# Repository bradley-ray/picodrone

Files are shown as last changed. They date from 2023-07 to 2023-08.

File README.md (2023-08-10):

# Pico Quadcopter Drone

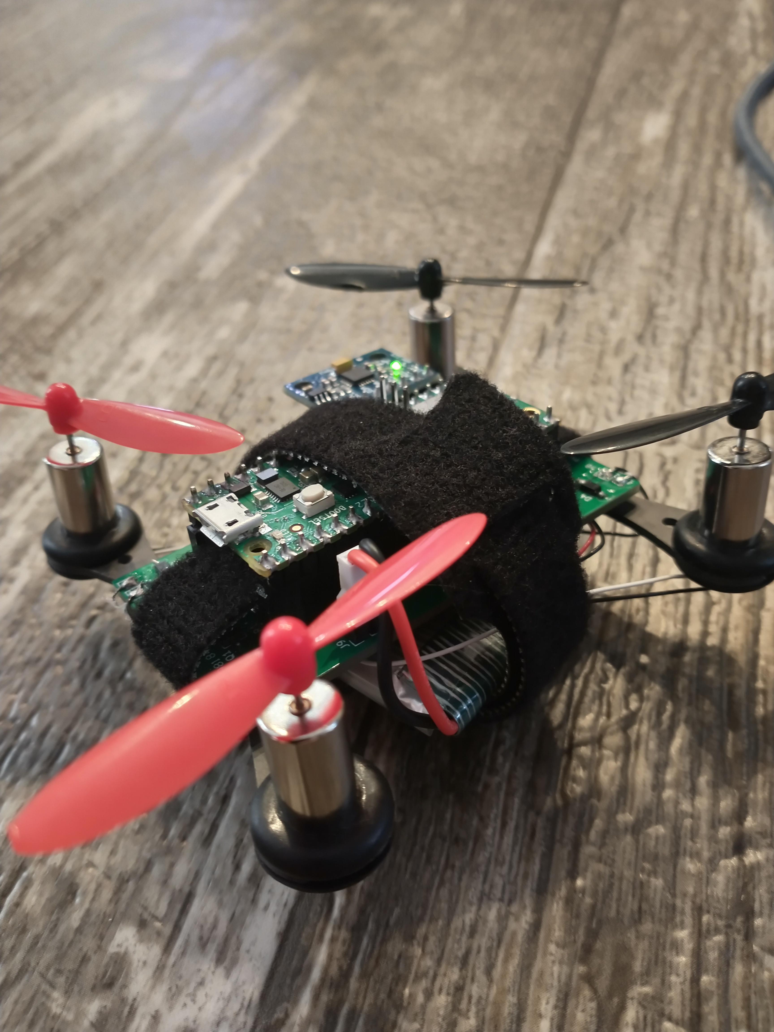
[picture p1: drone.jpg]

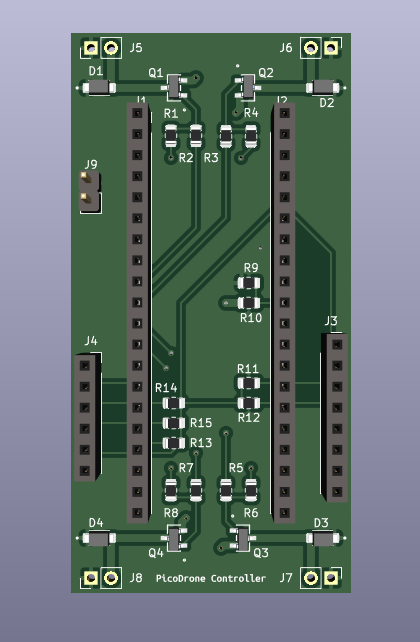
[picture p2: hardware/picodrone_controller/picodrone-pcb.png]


- `hardware/` contains the kicad schematic and pcb layout files 
    - qx95 drone frame
    - 8520 brushed motors
    - header sockets for raspberry pi pico
    - header sockets for mpu 6050 breakout board
    - header sockets for sd card spi breakout board (future use)

- `firmware/` contains the code for the microcontroller
    - requires pico_sdk to be downloaded and PICO_SDK_PATH to be set
    - uses `btstack` and bluetooth rfcomm to receive control commands over bluetooth connection

- `app/` contains python script to send inputs from ps4 controller to drone
    - install `pyPS4Controller` and `pySerial`
    - find pico_w bt addr using `sdptool browse`
    - run `rfcomm connect /dev/rfcomm0 <btaddr>` to connect to the drone
    - run `python3 main.py rfcomm0`
    - connect ps4 controller
        - `triangle` - increase pitch
        - `cross` - decrease pitch
        - `square` - roll left
        - `circle` - roll right
        - `up arrow` - increase throttle
        - `down arrow` - decrease throttle
        - `left arrow` - yaw left
        - `right arrow` - yaw right

## TODO
- need to fix value drift on imu
- need a filter or something for improved imu data
- need to continue and test and adjust pid values

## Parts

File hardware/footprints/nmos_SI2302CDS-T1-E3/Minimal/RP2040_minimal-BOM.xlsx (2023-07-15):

RP2040_minimal_r1 BOM
Item | Quantity | Reference | Part | Voltage | Current | Power | Material | Size | Tolerance | Manufacturer | Manuf. Part # | Description | Notes
1 | 3 | C1,C4,C17 | 10u | 16V |  |  | X5R | 0805_2012Metric | 10% | Murata | GRM21BR61C106KE15K | CAP CER 10UF 16V X5R 0805 | Or equivalent
2 | 2 | C2, C3 | 27p | 50V |  |  | C0G | 0402_1005Metric | 5% | Murata | GCM1555C1H270JA16D | CAP CER 27PF 50V C0G/NP0 0402 | Or equivalent
3 | 10 | C5, C6, C7, C9, C11, C12, C13, C14, C15, C16 | 100n | 25V |  |  | X7R | 0402_1005Metric | 10% | Murata | GRM155R71E104KE14J | CAP CER 0.1UF 25V X7R 0402 | Or equivalent
4 | 2 | C8, C10 | 1u | 10V |  |  | X6S | 0402_1005Metric | 10% | Murata | GRM155C81A105KA12D | CAP CER 1UF 10V X6S 0402 | Or equivalent
5 | 1 | J1 | USB_B_Micro |  |  |  |  |  |  | Amphenol | 10103594-0001LF | CONN RCPT USB2.0 MICRO B SMD R/A | Or equivalent
6 | 1 | J2 | 1x2 way header |  |  |  |  |  |  | Samtec | TSW-102-23-T-S | 2.54mm pin header 1x2 | Or equivalent
7 | 2 | J3, J4 | 2x18 way header |  |  |  |  |  |  | Samtec | TSW-118-23-T-D | 2.54mm pin header 2x18 | Or equivalent
8 | 2 | R1, R5 | 1k |  |  | 63mW |  | 0402_1005Metric | 1% | Yageo | RC0402FR-071KP | RES SMD 1K OHM 1% 1/16W 0402 | Or equivalent
9 | 1 | R2 | DNF |  |  |  |  | 0402_1005Metric |  |  |  |  | Do Not Fit
10 | 2 | R3, R4 | 27.4 |  |  | 63mW |  | 0402_1005Metric | 1% | Yageo | RC0402FR-0727R4L | RES SMD 27.4 OHM 1% 1/16W 0402 | Or equivalent
11 | 1 | U1 | NCP1117-3.3 |  |  |  |  | SOT-223-3 |  | ON Semiconductor | NCP1117ST33T3G | IC REG LINEAR 3.3V 1A SOT223
12 | 1 | U2 | W25Q128JVS |  |  |  |  | SOIC-8 |  | Winbond | W25Q128JVSIQ TR | IC FLASH 128M SPI 133MHZ 8SOIC
13 | 1 | U3 | RP2040 |  |  |  |  | QFN56 |  | Raspberry Pi | RP2040
14 | 1 | Y1 | ABLS-12.000MHZ-B4-T |  |  |  |  | HC49-US |  | Abracon | ABLS-12.000MHZ-B4-T | CRYSTAL 12.0000MHZ 18PF SMD

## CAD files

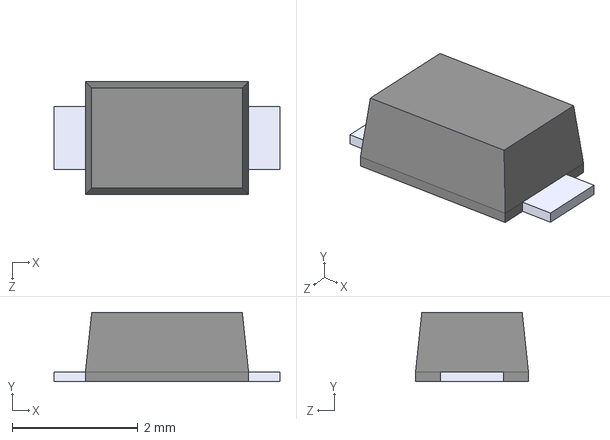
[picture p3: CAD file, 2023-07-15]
hardware/footprints/schottky_DSS16UTR/DSS16UTR.step
3.60 x 1.10 x 1.80 mm

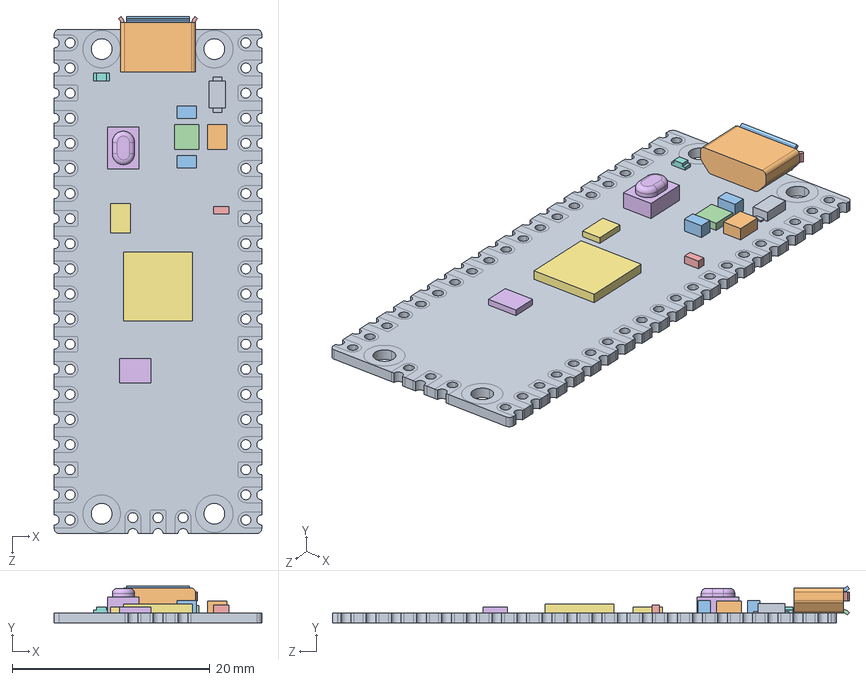
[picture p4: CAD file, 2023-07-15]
hardware/steps/pi-step/Pico-R3.step
21.0 x 3.73 x 52.3 mm
PICO_REF_BOARD.STEP
PICO_REF_USB.STEP
PICO_REF_SWITCH.STEP
PICO_REF_MICROCONTROLLER.STEP
PICO_REF_LED.STEP
PICO_REF_ONSEMI.STEP
PICO_BOURNS.STEP
PICO_MURATA.STEP x 2
PICO_RICHTEK.STEP
PICO_DIODES.STEP
PICO_AEL.STEP
PICO_WINBOND.STEP

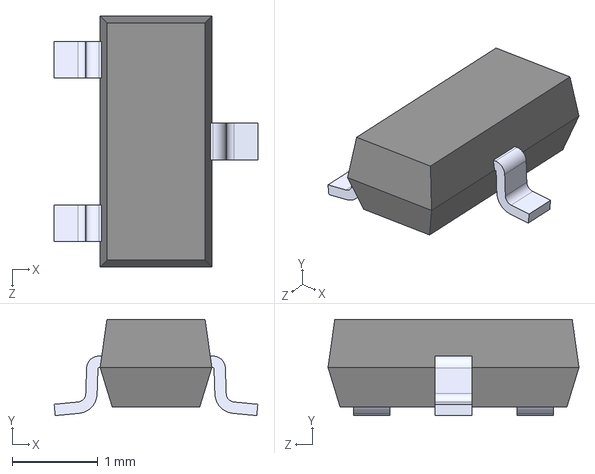
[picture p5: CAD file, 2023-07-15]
hardware/steps/nmos_SI2302CDS-T1-E3.STEP
2.37 x 1.12 x 2.92 mm

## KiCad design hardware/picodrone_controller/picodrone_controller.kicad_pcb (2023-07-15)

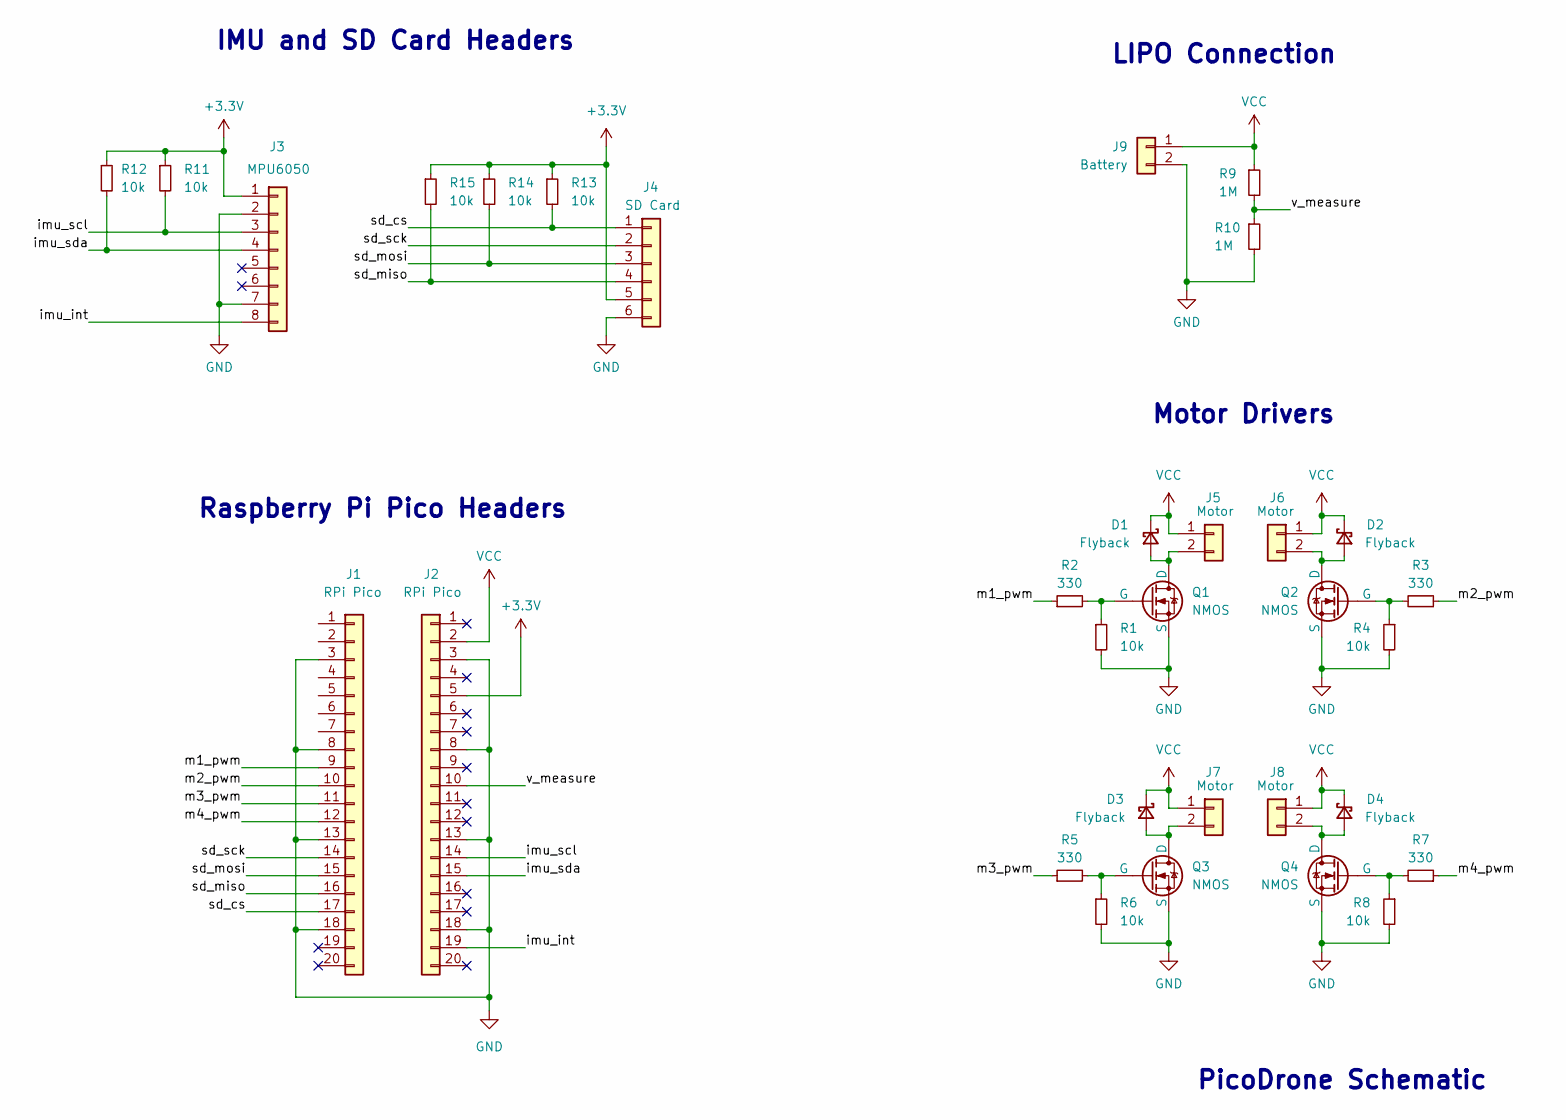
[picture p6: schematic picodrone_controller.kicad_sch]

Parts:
D1, D2, D3, D4: Flyback; SODFL3618X110N
J1, J2: RPi Pico; PinSocket_1x20_P2.54mm_Vertical
J3: MPU6050; PinSocket_1x08_P2.54mm_Vertical
J4: SD Card; PinSocket_1x06_P2.54mm_Vertical
J5, J6, J7, J8: Motor; PinHeader_1x02_P2.54mm_Vertical
J9: Battery; PinHeader_1x02_P2.54mm_Vertical
Q1, Q2, Q3, Q4: NMOS; TO-236_VIS
R1, R4, R6, R8, R11, R12, R13, R14, R15: 10k; R_0805_2012Metric
R2, R3, R5, R7: 330; R_0805_2012Metric
R9, R10: 1M; R_0805_2012Metric

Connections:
+3.3V: J2.5, J3.1, J4.5, R11.1, R12.1, R13.1, R14.1, R15.1
/imu_int: J2.19, J3.8
/imu_scl: J2.14, J3.3, R11.2
/imu_sda: J2.15, J3.4, R12.2
/m1_pwm: J1.9, R2.1
/m2_pwm: J1.10, R3.1
/m3_pwm: J1.11, R5.1
/m4_pwm: J1.12, R7.1
/sd_cs: J1.17, J4.1, R13.2
/sd_miso: J1.16, J4.4, R15.2
/sd_mosi: J1.15, J4.3, R14.2
/sd_sck: J1.14, J4.2
/v_measure: J2.10, R9.2, R10.1
GND: J1.3, J1.8, J1.13, J1.18, J2.3, J2.8, J2.13, J2.18, J3.2, J3.7, J4.6, J9.2, Q1.3 (S), Q2.3 (S), Q3.3 (S), Q4.3 (S), R1.2, R4.2, R6.2, R8.2, R10.2
unnamed: D1.2 (A), J5.2, Q1.1 (D)
unnamed: D2.2 (A), J6.2, Q2.1 (D)
unnamed: D3.2 (A), J7.2, Q3.1 (D)
unnamed: D4.2 (A), J8.2, Q4.1 (D)
unnamed: Q1.2 (G), R1.1, R2.2
unnamed: Q2.2 (G), R3.2, R4.1
unnamed: Q3.2 (G), R5.2, R6.1
unnamed: Q4.2 (G), R7.2, R8.1
VCC: D1.1 (K), D2.1 (K), D3.1 (K), D4.1 (K), J2.2, J5.1, J6.1, J7.1, J8.1, J9.1, R9.1

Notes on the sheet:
Motor Drivers
Raspberry Pi Pico Headers
PicoDrone Schematic
LIPO Connection
IMU and SD Card Headers

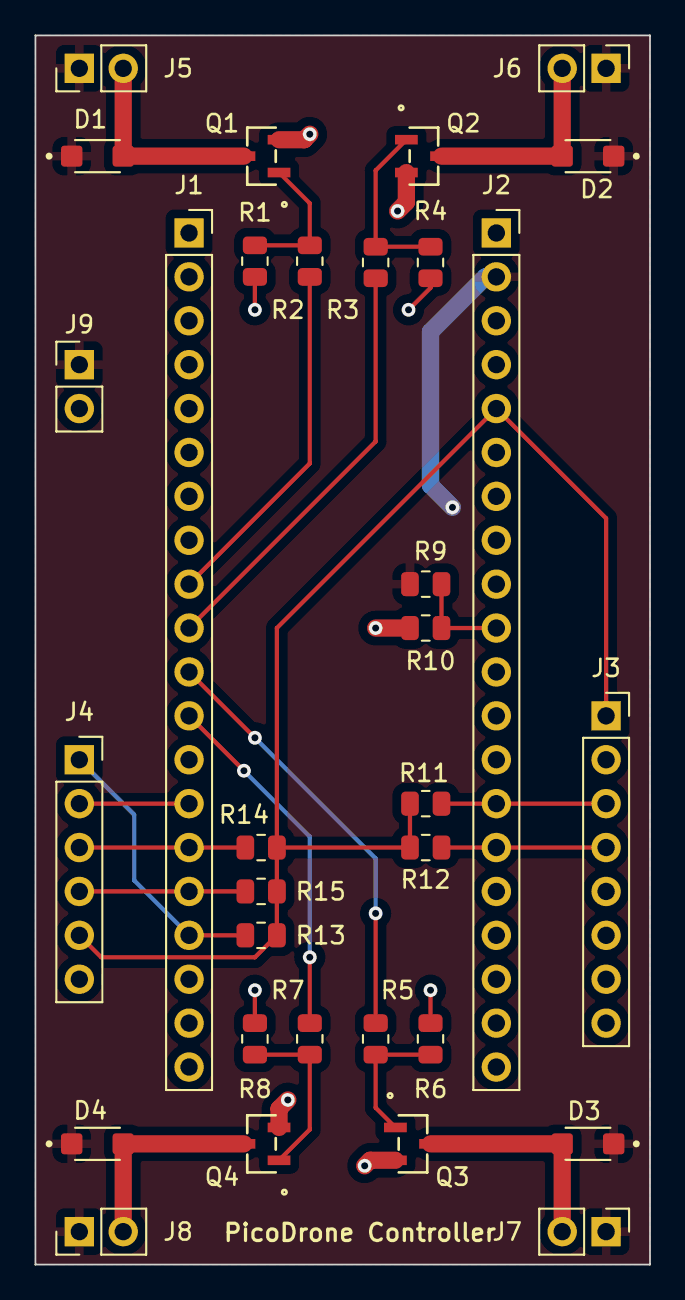
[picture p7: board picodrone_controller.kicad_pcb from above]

Board: 2 copper layers, 35.6 x 71.1 mm, 32 parts (0 on the bottom side), 22 nets.

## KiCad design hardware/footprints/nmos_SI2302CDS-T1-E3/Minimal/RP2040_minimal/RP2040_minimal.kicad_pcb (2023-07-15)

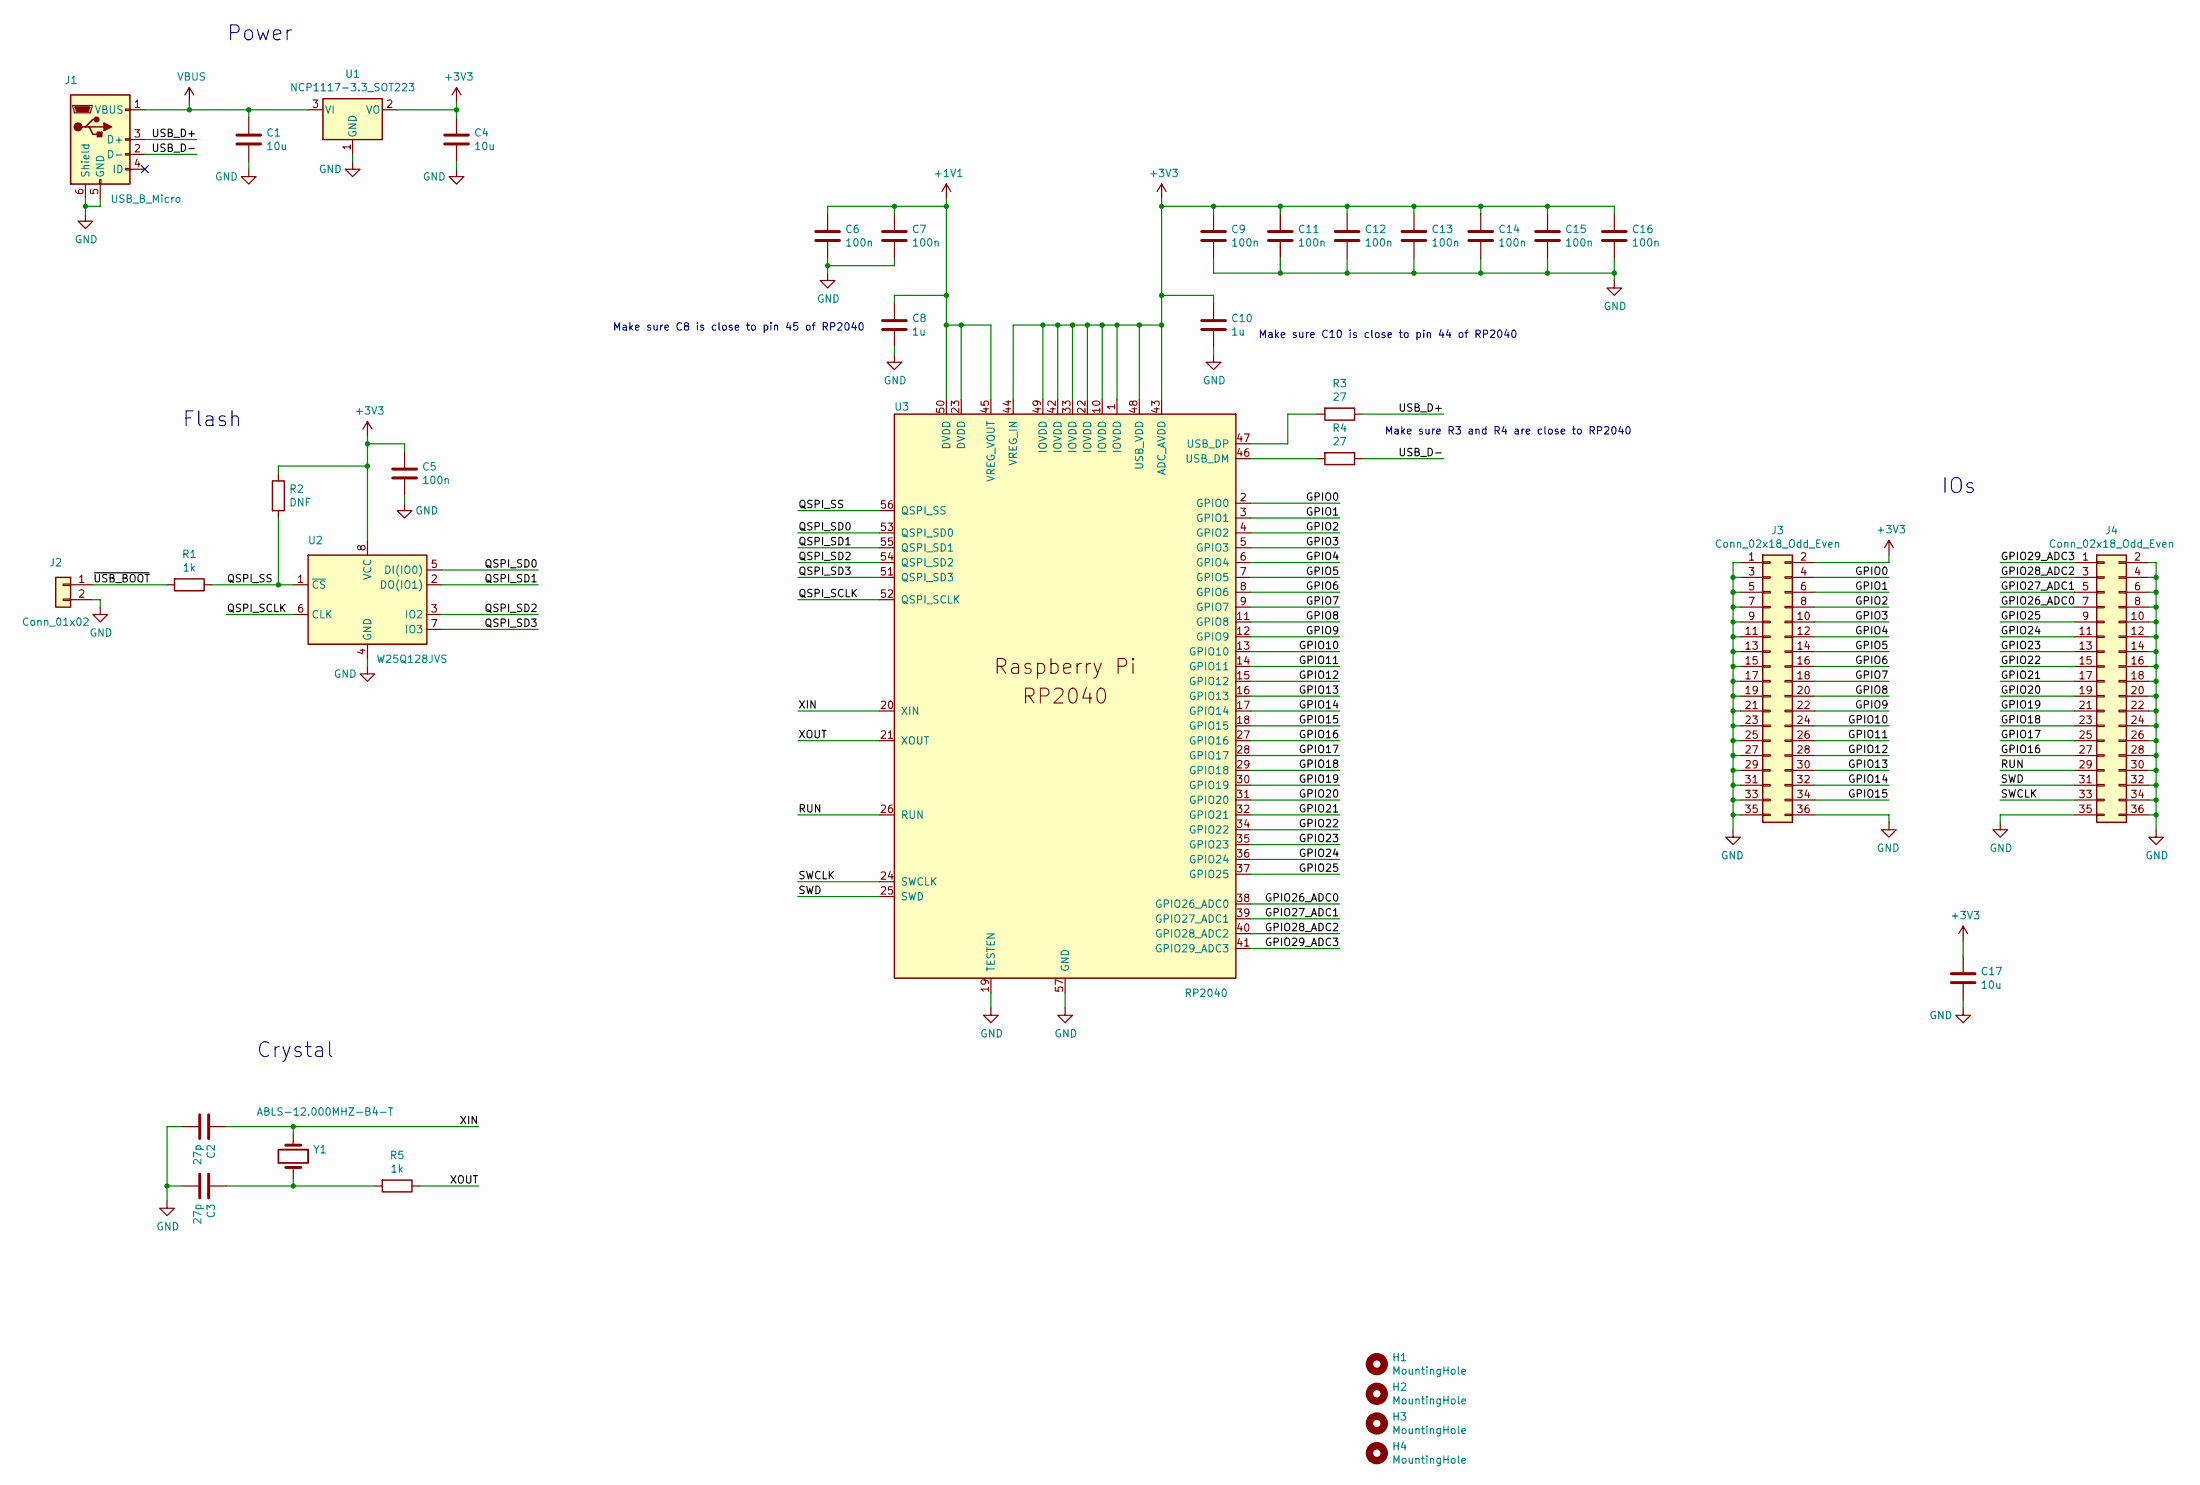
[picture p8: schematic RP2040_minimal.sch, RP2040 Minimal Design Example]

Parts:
C1, C4, C17: 10u; C_0805_2012Metric
C2, C3: 27p; C_0402_1005Metric
C5, C6, C7, C9, C11, C12, C13, C14, C15, C16: 100n; C_0402_1005Metric
C8, C10: 1u; C_0402_1005Metric
H1, H2, H3, H4: MountingHole; MountingHole_2.7mm_M2.5
J1: USB_B_Micro; USB_Micro-B_Amphenol_10103594-0001LF_Horizontal_modified
J2: Conn_01x02; PinHeader_1x02_P2.54mm_Vertical
J3, J4: Conn_02x18_Odd_Even; PinHeader_2x18_P2.54mm_Vertical
R1, R5: 1k; C_0402_1005Metric
R2: DNF; C_0402_1005Metric
R3, R4: 27; C_0402_1005Metric
U1: NCP1117-3.3_SOT223; SOT-223-3_TabPin2
U2: W25Q128JVS; SOIC-8_5.23x5.23mm_P1.27mm
U3: RP2040; RP2040-QFN-56
Y1: ABLS-12.000MHZ-B4-T; Crystal_SMD_HC49-US

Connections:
+1V1: C6.1, C7.1, C8.1, U3.23 (DVDD), U3.45 (VREG_VOUT), U3.50 (DVDD)
+3V3: C4.1, C5.1, C9.1, C10.1, C11.1, C12.1, C13.1, C14.1, C15.1, C16.1, C17.1, J3.2, R2.1, U1.2 (VO), U2.8 (VCC), U3.1 (IOVDD), U3.10 (IOVDD), U3.22 (IOVDD), U3.33 (IOVDD), U3.42 (IOVDD), U3.43 (ADC_AVDD), U3.44 (VREG_IN), U3.48 (USB_VDD), U3.49 (IOVDD)
/GPIO0: J3.4, U3.2 (GPIO0)
/GPIO1: J3.6, U3.3 (GPIO1)
/GPIO2: J3.8, U3.4 (GPIO2)
/GPIO3: J3.10, U3.5 (GPIO3)
/GPIO4: J3.12, U3.6 (GPIO4)
/GPIO5: J3.14, U3.7 (GPIO5)
/GPIO6: J3.16, U3.8 (GPIO6)
/GPIO7: J3.18, U3.9 (GPIO7)
/GPIO8: J3.20, U3.11 (GPIO8)
/GPIO9: J3.22, U3.12 (GPIO9)
/GPIO10: J3.24, U3.13 (GPIO10)
/GPIO11: J3.26, U3.14 (GPIO11)
/GPIO12: J3.28, U3.15 (GPIO12)
/GPIO13: J3.30, U3.16 (GPIO13)
/GPIO14: J3.32, U3.17 (GPIO14)
/GPIO15: J3.34, U3.18 (GPIO15)
/GPIO16: J4.27, U3.27 (GPIO16)
/GPIO17: J4.25, U3.28 (GPIO17)
/GPIO18: J4.23, U3.29 (GPIO18)
/GPIO19: J4.21, U3.30 (GPIO19)
/GPIO20: J4.19, U3.31 (GPIO20)
/GPIO21: J4.17, U3.32 (GPIO21)
/GPIO22: J4.15, U3.34 (GPIO22)
/GPIO23: J4.13, U3.35 (GPIO23)
/GPIO24: J4.11, U3.36 (GPIO24)
/GPIO25: J4.9, U3.37 (GPIO25)
/GPIO26_ADC0: J4.7, U3.38 (GPIO26_ADC0)
/GPIO27_ADC1: J4.5, U3.39 (GPIO27_ADC1)
/GPIO28_ADC2: J4.3, U3.40 (GPIO28_ADC2)
/GPIO29_ADC3: J4.1, U3.41 (GPIO29_ADC3)
/QSPI_SCLK: U2.6 (CLK), U3.52 (QSPI_SCLK)
/QSPI_SD0: U2.5 (DI(IO0)), U3.53 (QSPI_SD0)
/QSPI_SD1: U2.2 (DO(IO1)), U3.55 (QSPI_SD1)
/QSPI_SD2: U2.3 (IO2), U3.54 (QSPI_SD2)
/QSPI_SD3: U2.7 (IO3), U3.51 (QSPI_SD3)
/QSPI_SS: R1.1, R2.2, U2.1 (~CS), U3.56 (QSPI_SS)
/RUN: J4.29, U3.26 (RUN)
/SWCLK: J4.33, U3.24 (SWCLK)
/SWD: J4.31, U3.25 (SWD)
/USB_D+: J1.3 (D+), R3.1
/USB_D-: J1.2 (D-), R4.1
/XIN: C2.1, U3.20 (XIN), Y1.1
/XOUT: R5.1, U3.21 (XOUT)
/~USB_BOOT: J2.1, R1.2
GND: C1.2, C2.2, C3.2, C4.2, C5.2, C6.2, C7.2, C8.2, C9.2, C10.2, C11.2, C12.2, C13.2, C14.2, C15.2, C16.2, C17.2, J1.5 (GND), J1.6 (Shield), J2.2, J3.1, J3.3, J3.5, J3.7, J3.9, J3.11, J3.13, J3.15, J3.17, J3.19, J3.21, J3.23, J3.25, J3.27, J3.29, J3.31, J3.33, J3.35, J3.36, J4.2, J4.4, J4.6, J4.8, J4.10, J4.12, J4.14, J4.16, J4.18, J4.20, J4.22, J4.24, J4.26, J4.28, J4.30, J4.32, J4.34, J4.35, J4.36, U1.1 (GND), U2.4 (GND), U3.19 (TESTEN), U3.57 (GND)
unnamed: C3.1, R5.2, Y1.2
unnamed: R3.2, U3.47 (USB_DP)
unnamed: R4.2, U3.46 (USB_DM)
VBUS: C1.1, J1.1 (VBUS), U1.3 (VI)

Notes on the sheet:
Make sure C10 is close to pin 44 of RP2040
Make sure C8 is close to pin 45 of RP2040
Crystal
Flash
Power
IOs
Make sure R3 and R4 are close to RP2040

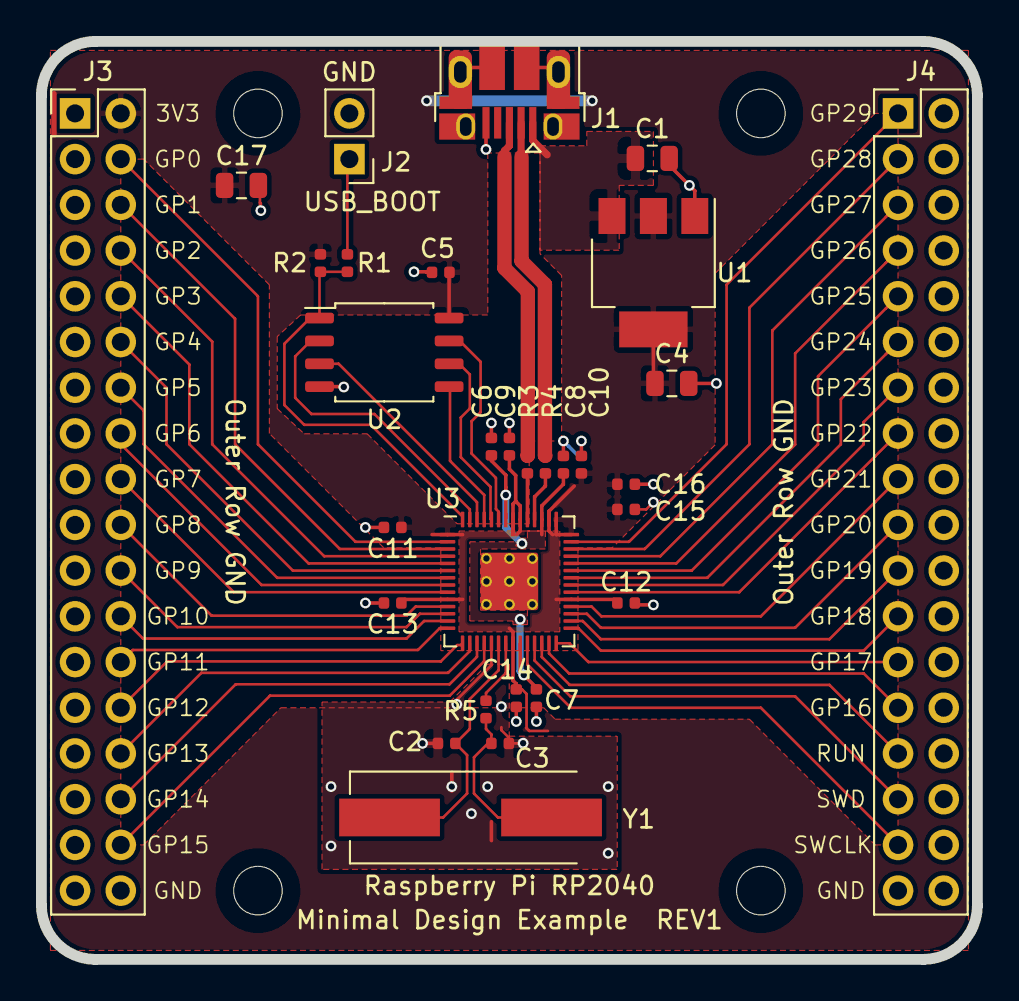
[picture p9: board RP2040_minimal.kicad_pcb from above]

Board: 2 copper layers, 52.0 x 51.0 mm, 34 parts (0 on the bottom side), 51 nets.

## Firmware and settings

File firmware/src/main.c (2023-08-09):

#include <stdio.h>

#include "pico/stdlib.h"
#include "pico/cyw43_arch.h"
#include "hardware/i2c.h"
#include "hardware/pwm.h"

#include "btstack.h"
#include "btstack_event.h"
#include "btstack_run_loop.h"

#include "bt.h"
#include "mpu.h"
#include "control.h"

void hardware_init(void);

// TODO: start with these pid values and tune as needed
pid_gain_t pitch_cfg = {
	.Kp = 1.2,
	.Ki = 0.02,
	.Kd = 15,
};

pid_gain_t roll_cfg = {
	.Kp = 1.2,
	.Ki = 0.02,
	.Kd = 15,
};

pid_gain_t yaw_cfg = {
	.Kp = 1.2,
	.Ki = 0.02,
	.Kd = 0,
};

int main() {
	hardware_init();
	printf("starting\n");
	mpu_init(MPU_ACCEL_4G, MPU_GYRO_500_DEG);
	pid_init(&pitch_cfg, &roll_cfg, &yaw_cfg);
	motors_init();
	printf("hello world\n");
	btstack_main(0, NULL);
	btstack_run_loop_execute();

	return 0;
}

void hardware_init(void) {
	stdio_init_all();
    cyw43_arch_init();

	// i2c setup for imu
	i2c_init(MPU_I2C_PORT, 100*1000);
	gpio_set_function(MPU_SDC_PIN, GPIO_FUNC_I2C);
	gpio_set_function(MPU_SDA_PIN, GPIO_FUNC_I2C);
	gpio_pull_up(MPU_SDC_PIN);
	gpio_pull_up(MPU_SDA_PIN);

	// pwm setup
    gpio_set_function(MOTOR_1_GPIO, GPIO_FUNC_PWM);
    gpio_set_function(MOTOR_2_GPIO, GPIO_FUNC_PWM);
    gpio_set_function(MOTOR_3_GPIO, GPIO_FUNC_PWM);
    gpio_set_function(MOTOR_4_GPIO, GPIO_FUNC_PWM);
}

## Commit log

2023-07-11 initial kicad project
    [picodrone_controller.kicad_pcb, picodrone_controller.kicad_sch]
2023-07-12 initial schematic
    [picodrone_controller.kicad_sch]
2023-07-14 rearrange schematic to help with pcb layout
    [picodrone_controller.kicad_sch]
2023-07-14 initial pcb layout
    [picodrone_controller.kicad_pcb]
2023-07-15 generated gerbers and ordered
    [DSS16UTR.step, Pico-R3.step, RP2040_minimal-BOM.xlsx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]
2023-07-29 add pcb and assembled photos
2023-07-30 add hello world to pico
2023-08-04 test mpu with bluetooth timers
2023-08-08 starting code for motor control
2023-08-09 fix pinout and bt packet type casting issue
    [main.c]
2023-08-09 update readme with current progress
2023-08-09 fix pitch, roll, yaw directions
2023-08-10 add fully assembled picture
